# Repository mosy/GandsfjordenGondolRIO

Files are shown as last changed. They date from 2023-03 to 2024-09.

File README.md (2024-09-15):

# Gandsfjorden Gondol RIO
## 17.08.24 Skjema for RIO
Logo Title Text 1
Logo Title Text 1
## 07.08.24 V2 prototype ankommet
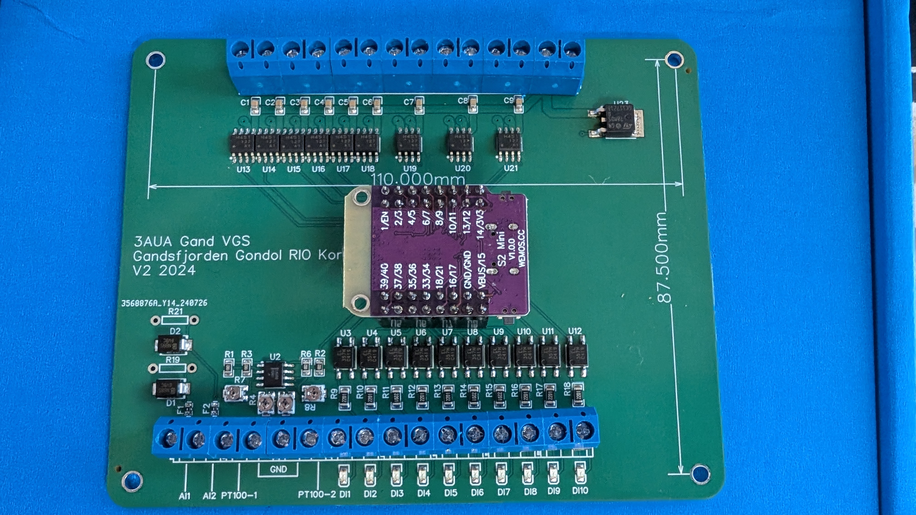
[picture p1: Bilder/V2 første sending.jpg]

Feil etter IO-sjekk:
1 pinne 39/40 er ikke analog inngang, fikses ved av vi bare trenger 1 AI og en PT1000 inngang PT1000 Kobles mot AI2
2 Mangler elektrolytt kondensator, fungerer fint uten
3 hol til skruer er 3.0. settes til 3.1 i neste versjon. 

## 06.09.23

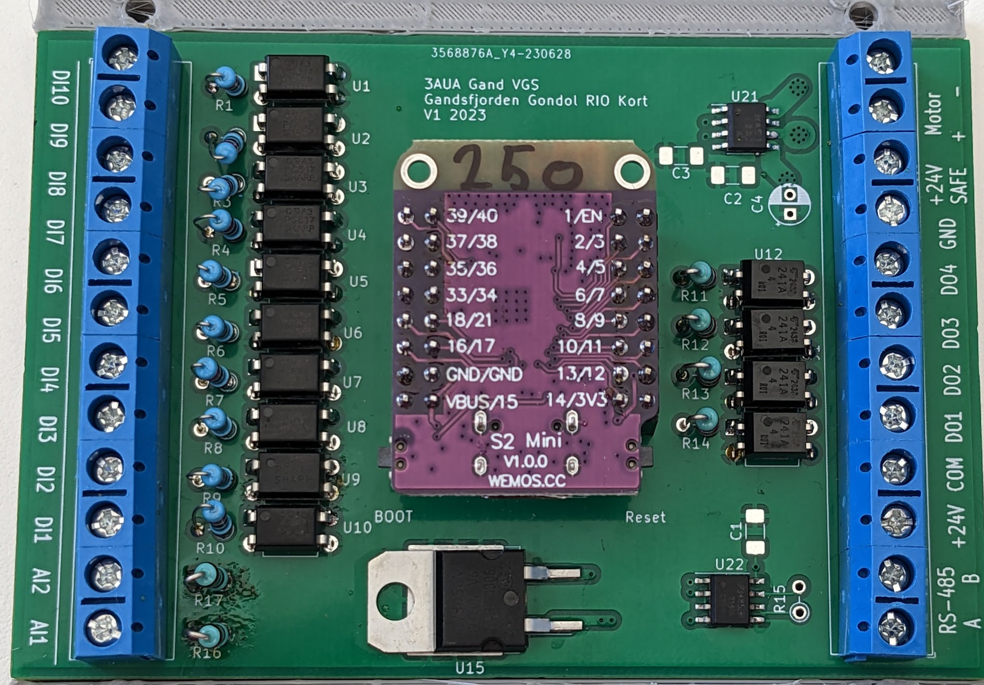
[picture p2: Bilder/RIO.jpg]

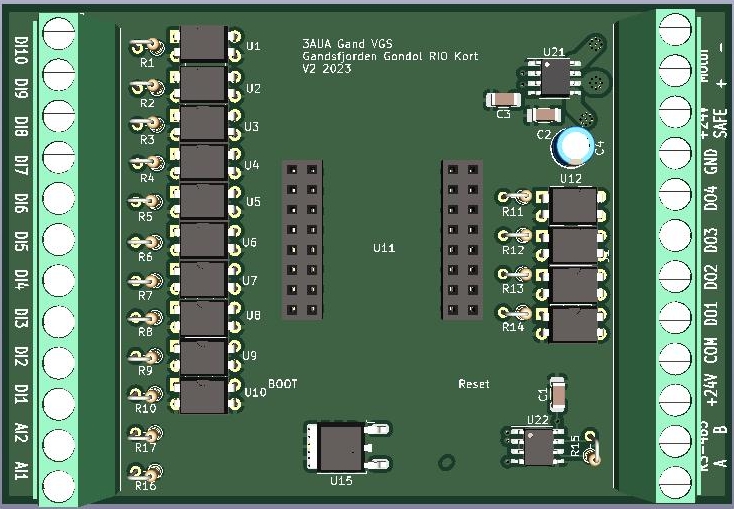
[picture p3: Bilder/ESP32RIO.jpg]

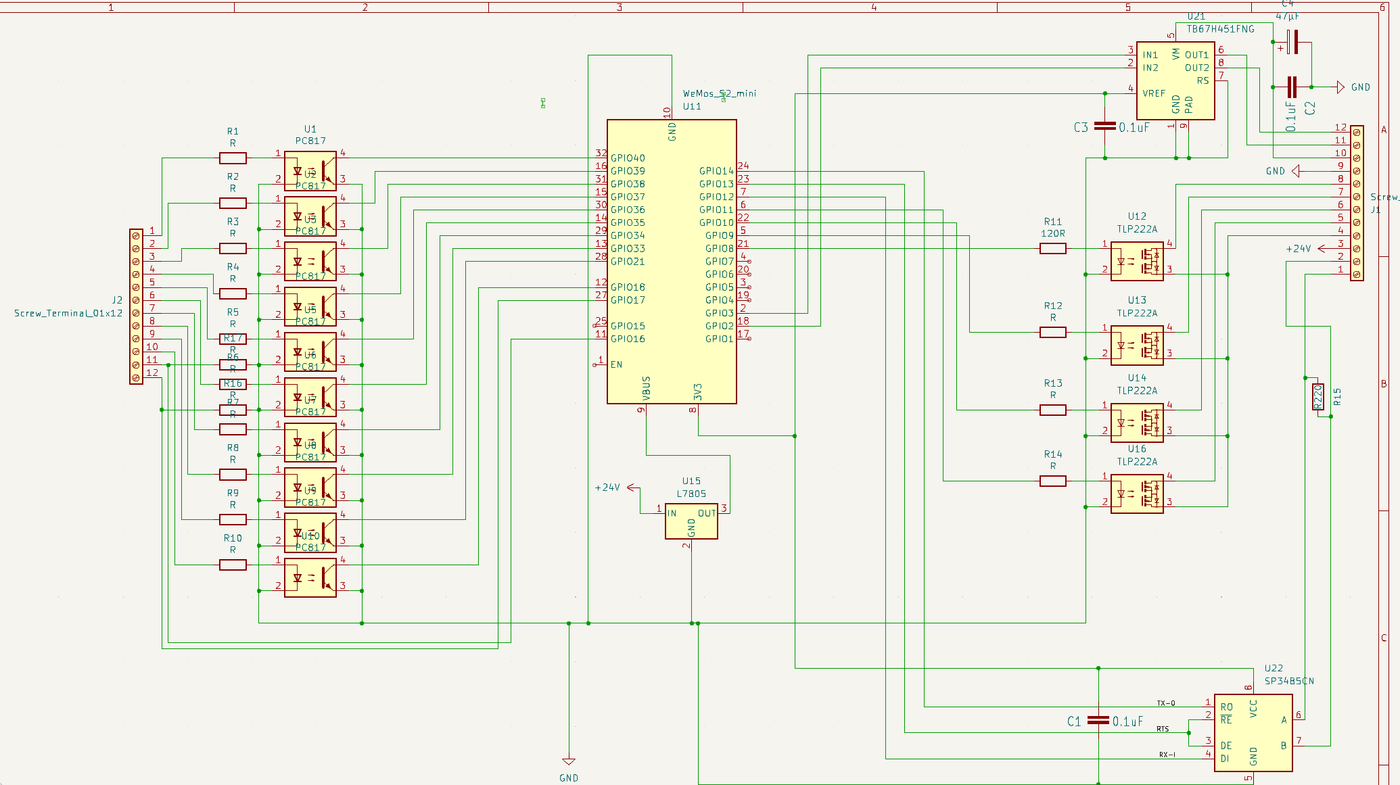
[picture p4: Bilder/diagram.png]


A simple Remote In Out training modeule to interface 24V industrial signals to a modbus PLC. 

Logo Title Text 1
 GandsfjordenGondolRIO

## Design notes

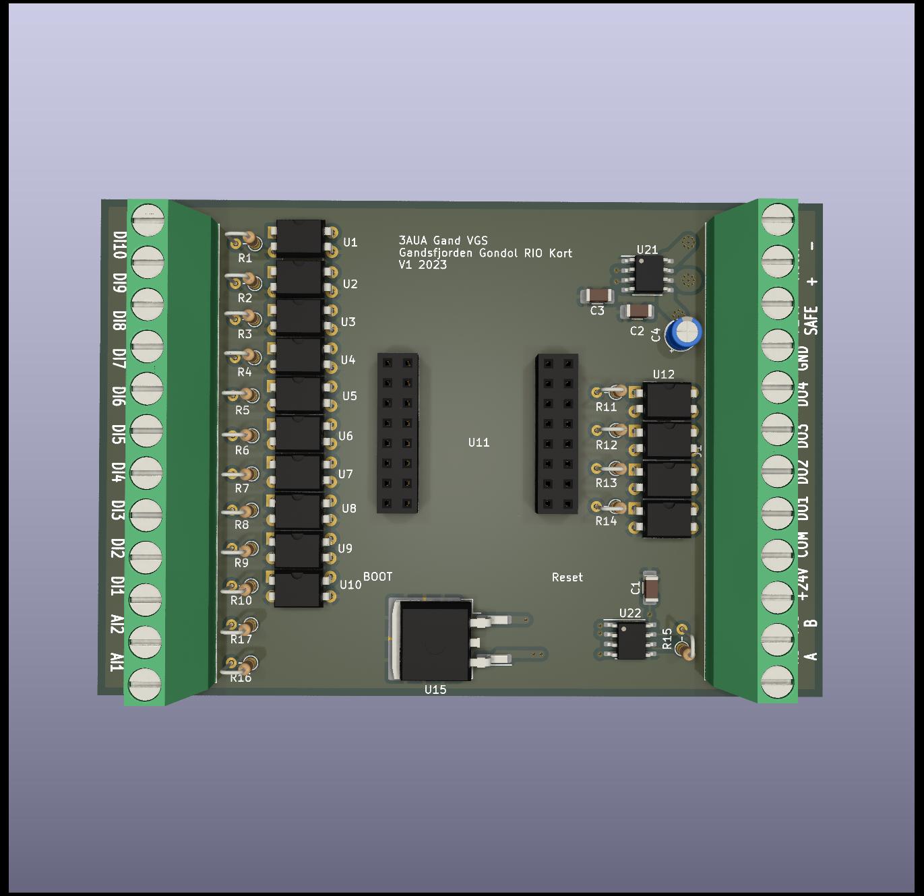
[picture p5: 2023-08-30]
Bilder/ESP32RIO2.jpg

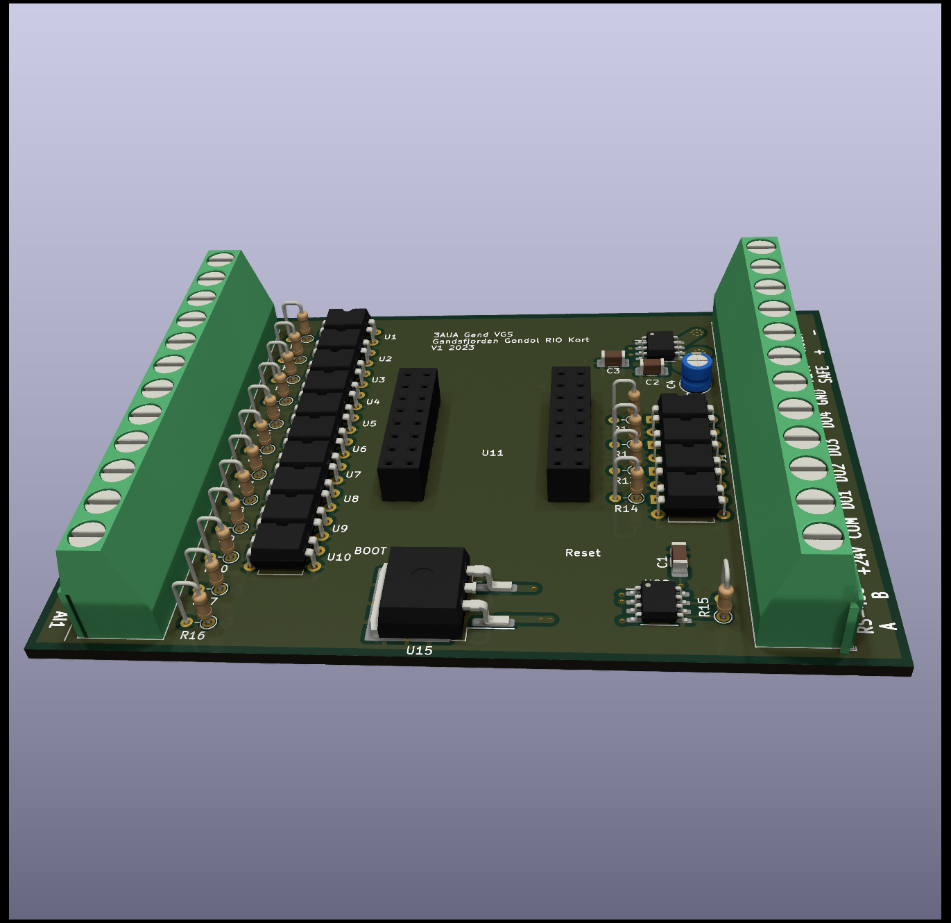
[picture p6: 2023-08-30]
Bilder/ESP32RIO.png

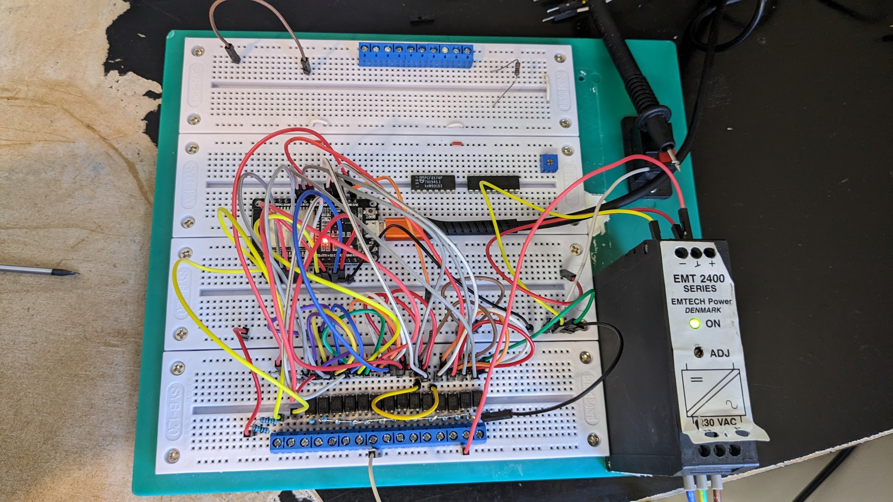
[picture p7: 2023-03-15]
Bilder/Oppkobling.jpg

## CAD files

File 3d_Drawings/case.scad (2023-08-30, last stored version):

// Card
width=95;
depth=65;
height=1.65;
//translate([0,0,1.65])cube([width,depth,height],center=true);



//Bottom box
boxwidth=95;
boxdepth=75;
boxheight=5;
difference(){
cube([boxwidth,boxdepth,boxheight],center=true);
translate([0,0,boxheight/2-1.75/2])cube([95+0.1,65,1.75],center=true);

translate([0,0,boxheight/2-3/2])cube([78,61,3],center=true);
//translate([0,0,boxheight/2-3/2])cylinder(20,1.5,center=true);
translate([0,0,boxheight/2-3/2])cylinder(20,1.5,center=true,$fn=6);
}

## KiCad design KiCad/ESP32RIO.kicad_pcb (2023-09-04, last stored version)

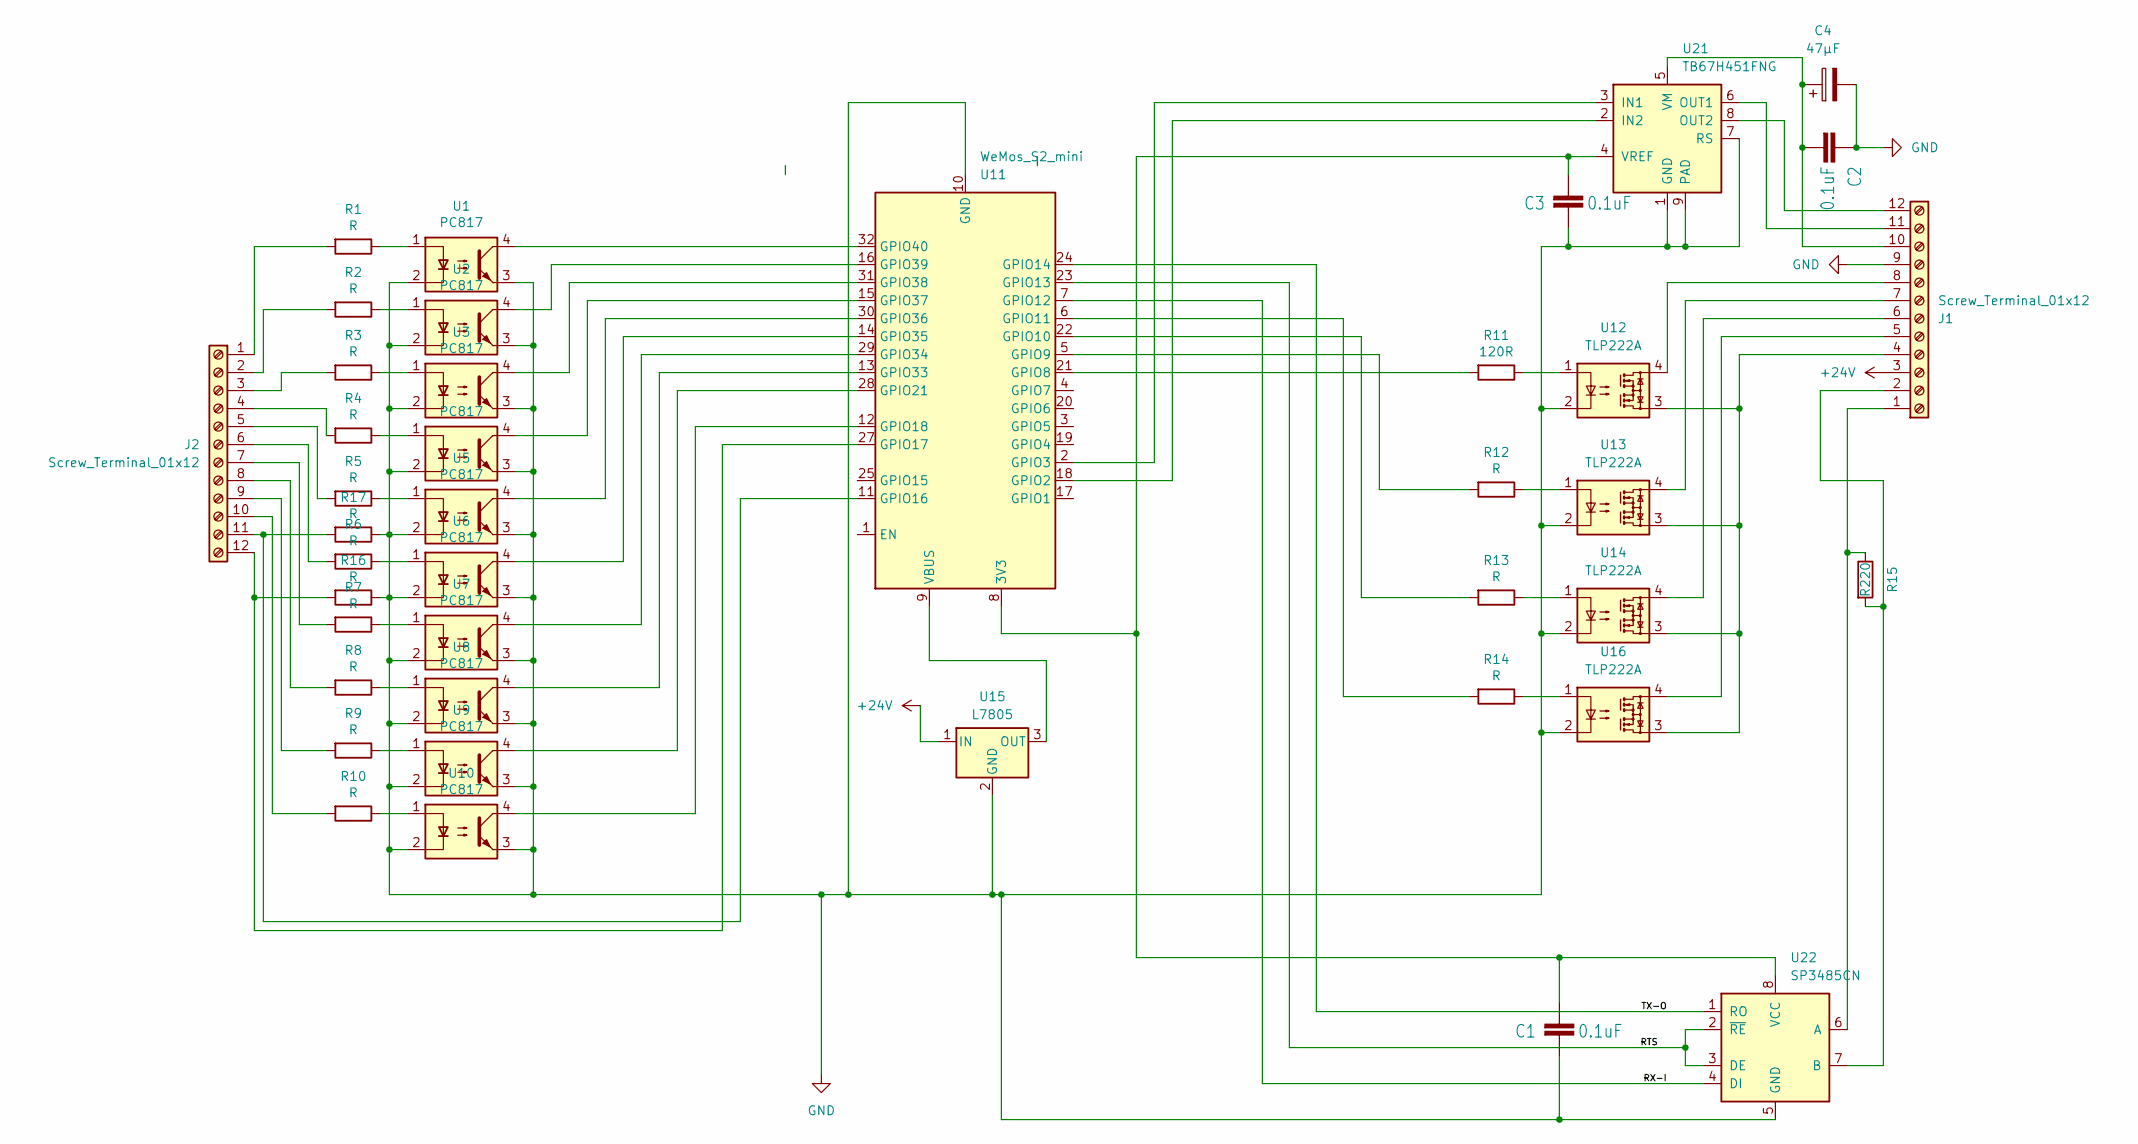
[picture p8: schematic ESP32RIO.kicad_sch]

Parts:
C1, C2, C3: 0.1uF; C_1206_3216Metric_Pad1.33x1.80mm_HandSolder
C4: 47µF; CP_Radial_D5.0mm_P2.50mm
J1, J2: Screw_Terminal_01x12; TerminalBlock_Phoenix_MKDS-1,5-12_1x12_P5.00mm_Horizontal
R1, R2, R3, R4, R5, R6, R7, R8, R9, R10, R12, R13, R14, R16, R17: R; R_Axial_DIN0204_L3.6mm_D1.6mm_P2.54mm_Vertical
R11: 120R; R_Axial_DIN0204_L3.6mm_D1.6mm_P2.54mm_Vertical
R15: R220; R_Axial_DIN0204_L3.6mm_D1.6mm_P2.54mm_Vertical
U1, U2, U3, U4, U5, U6, U7, U8, U9, U10: PC817; DIP-4_W7.62mm
U11: WeMos_S2_mini; WEMOS_S2_mini
U12, U13, U14, U16: TLP222A; DIP-4_W7.62mm
U15: L7805; TO-252-2
U21: TB67H451FNG; SOIC-8-1EP_3.9x4.9mm_P1.27mm_EP2.41x3.3mm
U22: SP3485CN; SOIC-8_3.9x4.9mm_P1.27mm

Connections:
+24V: J1.3, U15.1 (IN)
/RTS: U11.23 (GPIO13), U22.2 (~RE), U22.3 (DE)
/RX-I: U11.7 (GPIO12), U22.4 (DI)
/TX-O: U11.24 (GPIO14), U22.1 (RO)
GND: C1.2, C2.1, C3.2, C4.2, J1.9, R16.1, R17.1, U1.2, U1.3, U2.2, U2.3, U3.2, U3.3, U4.2, U4.3, U5.2, U5.3, U6.2, U6.3, U7.2, U7.3, U8.2, U8.3, U9.2, U9.3, U10.2, U10.3, U11.10 (GND), U11.26 (GND), U12.2, U13.2, U14.2, U15.2 (GND), U16.2, U21.1 (GND), U21.7 (RS), U21.9 (PAD), U22.5 (GND)
unnamed: J1.1, R15.1, U22.6 (A)
unnamed: J1.2, R15.2, U22.7 (B)
unnamed: J1.4, U12.3, U13.3, U14.3, U16.3
unnamed: J1.5, U16.4
unnamed: J1.6, U14.4
unnamed: J1.7, U13.4
unnamed: J1.8, U12.4
unnamed: C2.2, C4.1, J1.10, U21.5 (VM)
unnamed: J1.11, U21.6 (OUT1)
unnamed: J1.12, U21.8 (OUT2)
unnamed: J2.1, R1.2
unnamed: J2.2, R2.2
unnamed: J2.3, R3.2
unnamed: J2.4, R4.2
unnamed: J2.5, R5.2
unnamed: J2.6, R6.2
unnamed: J2.7, R7.2
unnamed: J2.8, R8.2
unnamed: J2.9, R9.2
unnamed: J2.10, R10.2
unnamed: J2.11, R17.2, U11.11 (GPIO16)
unnamed: J2.12, R16.2, U11.27 (GPIO17)
unnamed: R1.1, U1.1
unnamed: R2.1, U2.1
unnamed: R3.1, U3.1
unnamed: R4.1, U4.1
unnamed: R5.1, U5.1
unnamed: R6.1, U6.1
unnamed: R7.1, U7.1
unnamed: R8.1, U8.1
unnamed: R9.1, U9.1
unnamed: R10.1, U10.1
unnamed: R11.1, U12.1
unnamed: R12.1, U13.1
unnamed: R13.1, U14.1
unnamed: R14.1, U16.1
unnamed: C1.1, C3.1, U11.8 (3V3), U21.4 (VREF), U22.8 (VCC)
unnamed: U11.18 (GPIO2), U21.2 (IN2)
unnamed: U11.2 (GPIO3), U21.3 (IN1)
unnamed: R11.2, U11.21 (GPIO8)
unnamed: R12.2, U11.5 (GPIO9)
unnamed: R13.2, U11.22 (GPIO10)
unnamed: R14.2, U11.6 (GPIO11)
unnamed: U10.4, U11.12 (GPIO18)
unnamed: U9.4, U11.28 (GPIO21)
unnamed: U8.4, U11.13 (GPIO33)
unnamed: U7.4, U11.29 (GPIO34)
unnamed: U6.4, U11.14 (GPIO35)
unnamed: U5.4, U11.30 (GPIO36)
unnamed: U4.4, U11.15 (GPIO37)
unnamed: U3.4, U11.31 (GPIO38)
unnamed: U2.4, U11.16 (GPIO39)
unnamed: U1.4, U11.32 (GPIO40)
unnamed: U11.9 (VBUS), U15.3 (OUT)

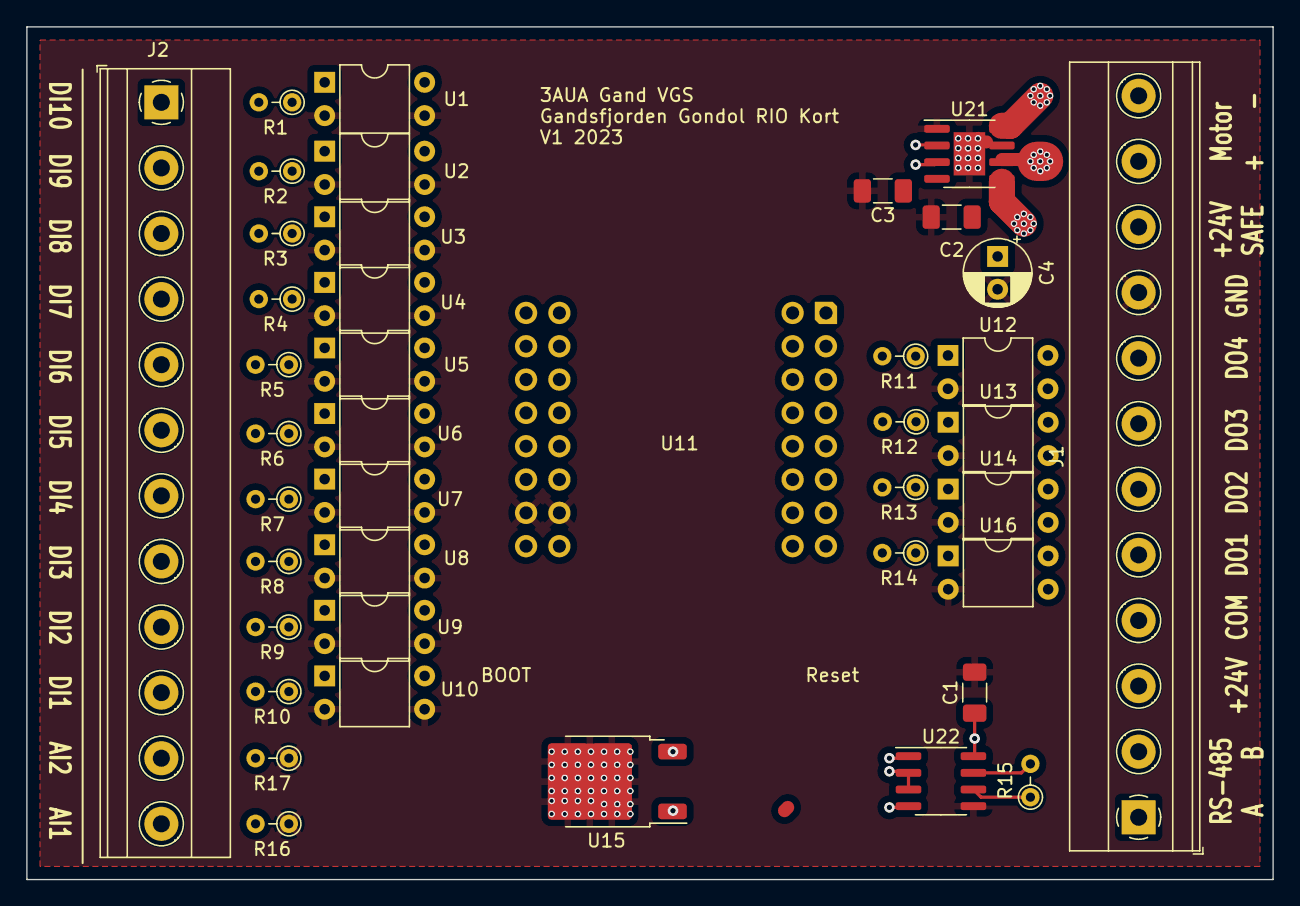
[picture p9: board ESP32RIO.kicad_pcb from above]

Board: 4 copper layers, 95.0 x 65.0 mm, 41 parts (1 on the bottom side), 59 nets.

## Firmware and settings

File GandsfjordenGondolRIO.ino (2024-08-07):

/*
  Modbus-Arduino Example - Test Holding Register (Modbus IP ESP8266)
  Configure Holding Register (offset 100) with initial value 0xABCD
  You can get or set this holding register
  Original library
  Copyright by André Sarmento Barbosa
  http://github.com/andresarmento/modbus-arduino

  Current version
  (c)2017 Alexander Emelianov (a.m.emelianov@gmail.com)
  https://github.com/emelianov/modbus-esp8266
*/

//#ifdef ESP8266
// #include <ESP8266WiFi.h>
//#else //ESP32
 #include <WiFi.h>
//#endif
#include <ModbusIP_ESP8266.h>
#include "arduino_secrets.h"
//#include "PCF8574.h"  // https://github.com/xreef/PCF8574_library

//PCF8574 pcf8574(0x20);
//Modbus Registers Offsets
//Used Pins
const int DI1 = 38; //GPIO0
const int DI2 = 37; //GPIO0
const int DI3 = 36; //GPIO0
const int DI4 = 35; //GPIO0
const int DI5 = 33; //GPIO0
const int DI6 = 34; //GPIO0
const int DI7 = 18; //GPIO0
const int DI8 = 21; //GPIO0
const int DI9 = 16; //GPIO0
const int DI10 = 17; //GPIO0

const int AI1 = 13; //GPIO0
const int AI2 = 14; //GPIO0

const int PT1 = 40; //GPIO0
const int PT2 = 39; //GPIO0

const int DO1 = 1; //GPIO0
const int DO2 = 2; //GPIO0
const int DO3 = 3; //GPIO0
const int DO4 = 4; //GPIO0
const int DO5 = 5; //GPIO0
const int DO6 = 6; //GPIO0
const int DO7m = 7; //GPIO0
const int DO7p = 9; //GPIO0
const int DO8m = 8; //GPIO0
const int DO8p = 11; //GPIO0
const int DO9m = 10; //GPIO0
const int DO9p = 12; //GPIO0


//const int MCW = 2; //GPIO0
//const int MCCW = 3; //GPIO0

// Modbus Registers Offsets
const int TEST_HREG = 1;

IPAddress staticIP(192, 168, 0, 207);
IPAddress gateway(192, 168, 0, 1);
IPAddress subnet(255, 255, 255, 0);
IPAddress dns(192,168,0,1);   //optional
//IPAddress secondaryDNS(8, 8, 4, 4); //optional
//ModbusIP object
ModbusIP mb;
  
void setup() {
  Serial.begin(115200);
 
 if (WiFi.config(staticIP, gateway, subnet, dns, dns) == false)
    Serial.println("Configuration failed.");
  //WiFi.begin("your_ssid", "your_password");
  WiFi.begin(SECRET_SSID, SECRET_PASS);
  
  while (WiFi.status() != WL_CONNECTED) {
    delay(500);
    Serial.print(".");
  }
 
  Serial.println("");
  Serial.println("WiFi connected");  
  Serial.println("IP address: ");
  Serial.println(WiFi.localIP());

mb.server();
mb.addIsts(1,false,11);
mb.addCoil(1,false,10);
mb.addHreg(1,0,2);
mb.addIreg(1,0,2);




//Set ledPin mode
	pinMode(DI1, INPUT_PULLUP);
	pinMode(DI2, INPUT_PULLUP);
	pinMode(DI3, INPUT_PULLUP);
	pinMode(DI4, INPUT_PULLUP);
	pinMode(DI5, INPUT_PULLUP);
	pinMode(DI6, INPUT_PULLUP);
	pinMode(DI7, INPUT_PULLUP);
	pinMode(DI8, INPUT_PULLUP);
	pinMode(DI9, INPUT_PULLUP);
	pinMode(DI10, INPUT_PULLUP);
	
	pinMode(AI1, INPUT);
	pinMode(AI2, INPUT);

	pinMode(PT1, INPUT);
	pinMode(PT2, INPUT);

	pinMode(DO1, OUTPUT);
	pinMode(DO2, OUTPUT);
	pinMode(DO3, OUTPUT);
	pinMode(DO4, OUTPUT);
	pinMode(DO5, OUTPUT);
	pinMode(DO6, OUTPUT);
	pinMode(DO7m, OUTPUT);
	pinMode(DO7p, OUTPUT);
	pinMode(DO8m, OUTPUT);
	pinMode(DO8p, OUTPUT);
	pinMode(DO9m, OUTPUT);
	pinMode(DO9p, OUTPUT);
	pinMode(15, OUTPUT);

	//pinMode(MCW, OUTPUT);
	//pinMode(MCCW, OUTPUT);
	ledcAttach(DO9m, 1000, 8);
	ledcAttach(DO9p, 1000, 8);

}
 
void loop() {
   //Call once inside loop() - all magic here
   mb.task();
    //Attach DI1 to SWITCH_ISTS register
	mb.Ists(1, !digitalRead(DI1));
	mb.Ists(2, !digitalRead(DI2));
	mb.Ists(3, !digitalRead(DI3));
	mb.Ists(4, !digitalRead(DI4));
	mb.Ists(5, !digitalRead(DI5));
	mb.Ists(6, !digitalRead(DI6));
	mb.Ists(7, !digitalRead(DI7));
	mb.Ists(8, !digitalRead(DI8));
	mb.Ists(9, !digitalRead(DI9));
	mb.Ists(10, !digitalRead(DI10));
	mb.Ists(11, digitalRead(PT2));

	mb.Ireg(1, analogRead(AI1));
	mb.Ireg(2, analogRead(AI2));
//	mb.Ireg(3, analogRead(PT1));
//	mb.Ireg(4, analogRead(PT2));

	digitalWrite(DO1, !mb.Coil(1));
	digitalWrite(DO2, !mb.Coil(2));
	digitalWrite(DO3, !mb.Coil(3));
	digitalWrite(DO4, !mb.Coil(4));
	digitalWrite(DO5, !mb.Coil(5));
	digitalWrite(DO6, !mb.Coil(6));
	digitalWrite(DO7p, mb.Coil(7));
	digitalWrite(DO7m, mb.Coil(8));
	digitalWrite(DO8p, mb.Coil(9));
	digitalWrite(DO8m, mb.Coil(10));
//	digitalWrite(DO9m, mb.Coil(11));
//	digitalWrite(DO9p, mb.Coil(12));
	
	ledcWrite(DO9m, mb.Hreg(1));
	ledcWrite(DO9p, mb.Hreg(2));
	if (WiFi.status() == WL_CONNECTED)
		digitalWrite(15, true);
		else 
		digitalWrite(15, false);
	
//  Serial.println(mb.Hreg(1));
//  Serial.println(mb.Hreg(2));
}

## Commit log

2023-03-14 Startet på skjema
    [ESP32RIO.kicad_pcb, ESP32RIO.kicad_sch, ESP32RIOEnkel.kicad_sch]
2023-03-15 14DI og 2 AI virker
    [ESP32RIO.kicad_pcb, ESP32RIO.kicad_sch]
2023-03-17 Lagt til utganger og funnet problemer med 4-20mA ut
    [ESP32RIO.kicad_sch]
2023-07-15 lagt til bilde av kort
    [ESP32RIO.kicad_pcb]
2023-07-15 fix number error in ino file
    [GandsfjordenGondolRIO.ino]
2023-08-30 v1 sendt til produksjon
    [ESP32RIO.kicad_sch, case.scad]
2023-09-04 fix kondensator og regulator
    [ESP32RIO-B_Cu.gbr, ESP32RIO-B_Mask.gbr, ESP32RIO-B_Paste.gbr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]
